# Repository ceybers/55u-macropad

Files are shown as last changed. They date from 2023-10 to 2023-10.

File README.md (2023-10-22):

# 5½u Macropad

## 📻 Project Description

A macropad inspired by the look of the iconic beam spring keyboards of the '70s.

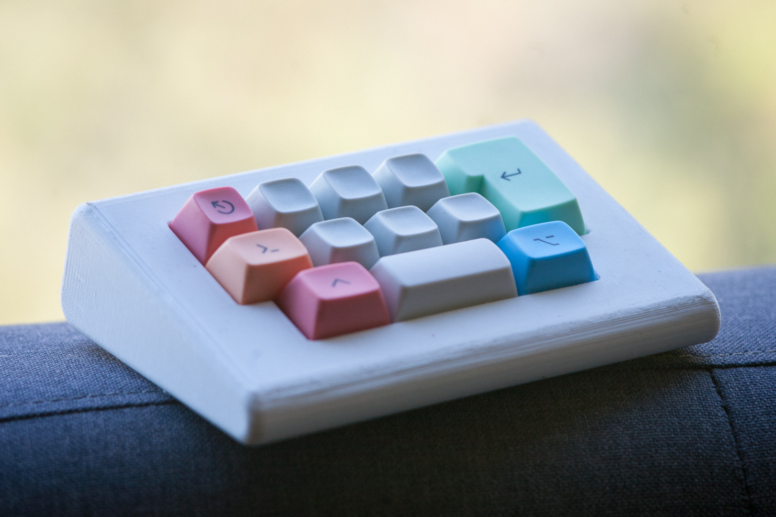
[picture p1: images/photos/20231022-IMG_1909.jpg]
Photo of the macro pad


## 🧰 Features

- 12× keys
- RP2040 microcontroller
- Powered by QMK with Vial support
- USB-C connector

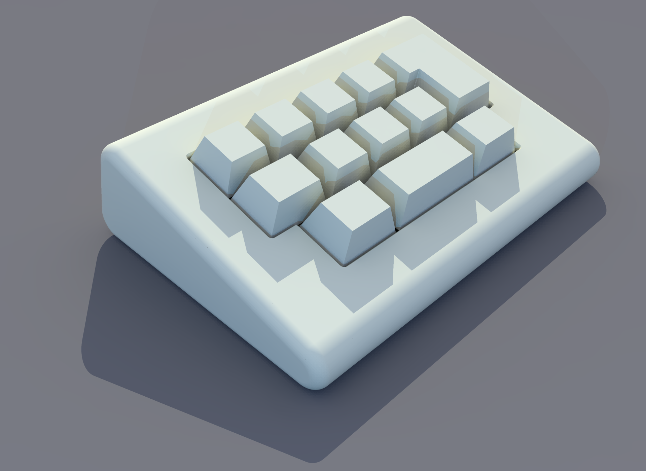
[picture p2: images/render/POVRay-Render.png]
Render using POVRay


## 📚 Read more...
- [Design](notes/Design.md)
- [Construction](notes/Construction.md)
- [Firmware](notes/Firmware.md)

---

## 🔗 Inspired by...
- [QAZER_BEAM](https://github.com/ImYourHuckleberry/QAZER_BEAM)
- [IBM Beam Spring Keyboards](https://deskthority.net/wiki/IBM_Beam_Spring_Keyboards#3275_.26_3277)
- [EzyezII Frankenstein](https://ezykeys.com/products/frankenstein-extensible-mini-mechanical-keyboard-kit)
- [Cary Works ViewEdge](https://drop.com/buy/cary-works-viewedge-display-and-c11-macropad)

## 📐 References
- [Raspberry Pi Pico Pinout](https://www.raspberrypi.com/documentation/microcontrollers/raspberry-pi-pico.html#pinout-and-design-files)
- [USB Type-C Breakout](https://www.pololu.com/product/3411)
- [QMK Firmware](https://docs.qmk.fm/)
- [Vial Firmware](https://get.vial.today/)

---

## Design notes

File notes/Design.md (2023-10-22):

# Design
The original design was a macro pad coupled with a LCD screen that would resemble a '70s or '80s terminal with a small CRT screen set in a bulky case. After some to and fro I decided to focus on the keyboard only as a separate piece.

Heavily inspired by ImYourHuckleberry's [QAZER_BEAM](https://github.com/ImYourHuckleberry/QAZER_BEAM), the aim I had in mind was a macropad that had generous bezels, a significant slope, and oversized round fillets. While it would only have 12 keys, I still wanted the familiar silhouette of a vintage keyboard. Lastly, I wanted the profile to hide the actual switches, with the keycaps sitting almost flush with the top surface.

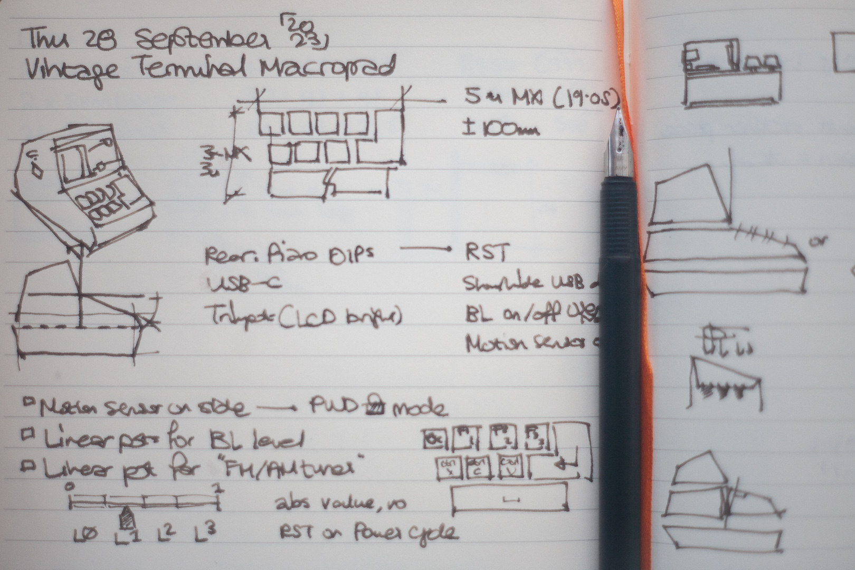
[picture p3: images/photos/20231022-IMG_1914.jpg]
Pen and paper sketch #1


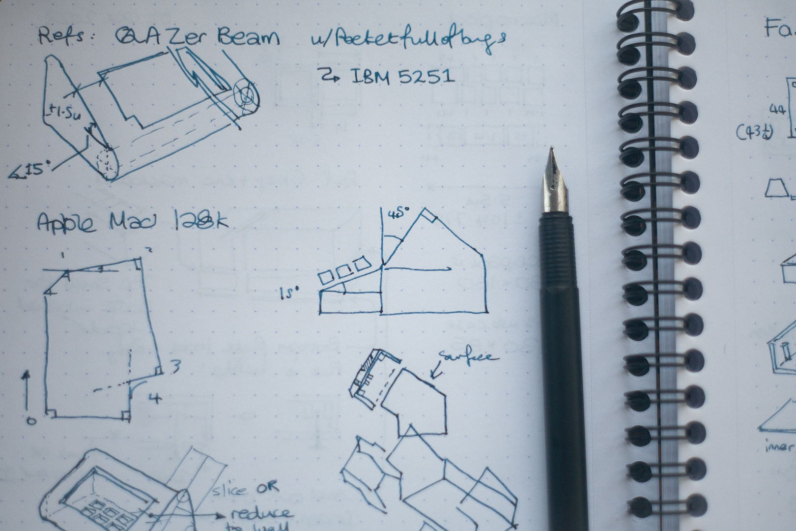
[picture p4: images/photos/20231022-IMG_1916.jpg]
Pen and paper sketch #2


Once I finished the pen and paper drafting and had a better idea of what I wanted, I used FreeCAD to create the models. 

I decided to create the case as one body, with the plate for the key switches being a separate part. It would be inserted from below and secured using screws into heat-set inserts that would be mounted inside and under the bezels of the case.

The bottom plate, which would be slightly wider than the switch plate, would then follow behind it and be secured in a similar fashion. I did not want the bottom plate visible from the sides, so I placed the heat-set inserts so that the bottom plate would sit sligthly inset into the case once secured.

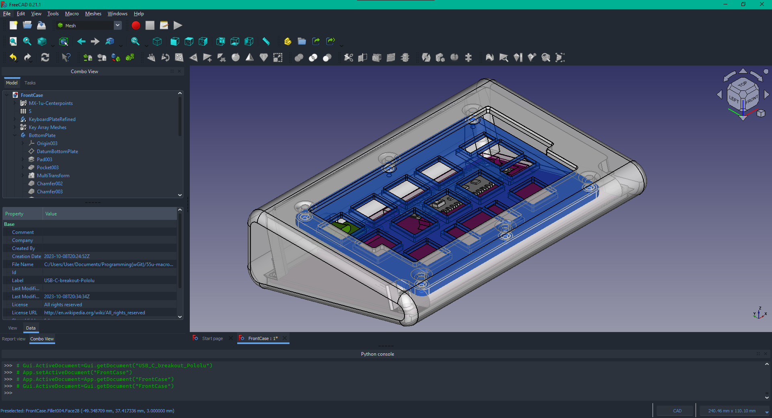
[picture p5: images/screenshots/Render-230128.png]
Render of the macro pad


---

Next: [Construction](Construction.md) | Back to [README.md](../README.md)

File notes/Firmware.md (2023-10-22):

# Firmware
## QMK and Vial
For the firmware I first used the official [QMK](https://docs.qmk.fm/) repo to ensure everything is working and wired up correctly. Once I had the QMK firmware working and flashed to the board, I installed the [Vial](https://get.vial.today/) fork of QMK, and created a Vial-compatible firmware using their instructions.

My initial attempt was to run QMK in a Docker container and then Vial in a separate container, but after some headscratching I instead spun up a new Linux LXC and just cloned both repos without using Docker.

I included the compiled firmware (`55u_macropad_vial.uf2`) for convenience. 

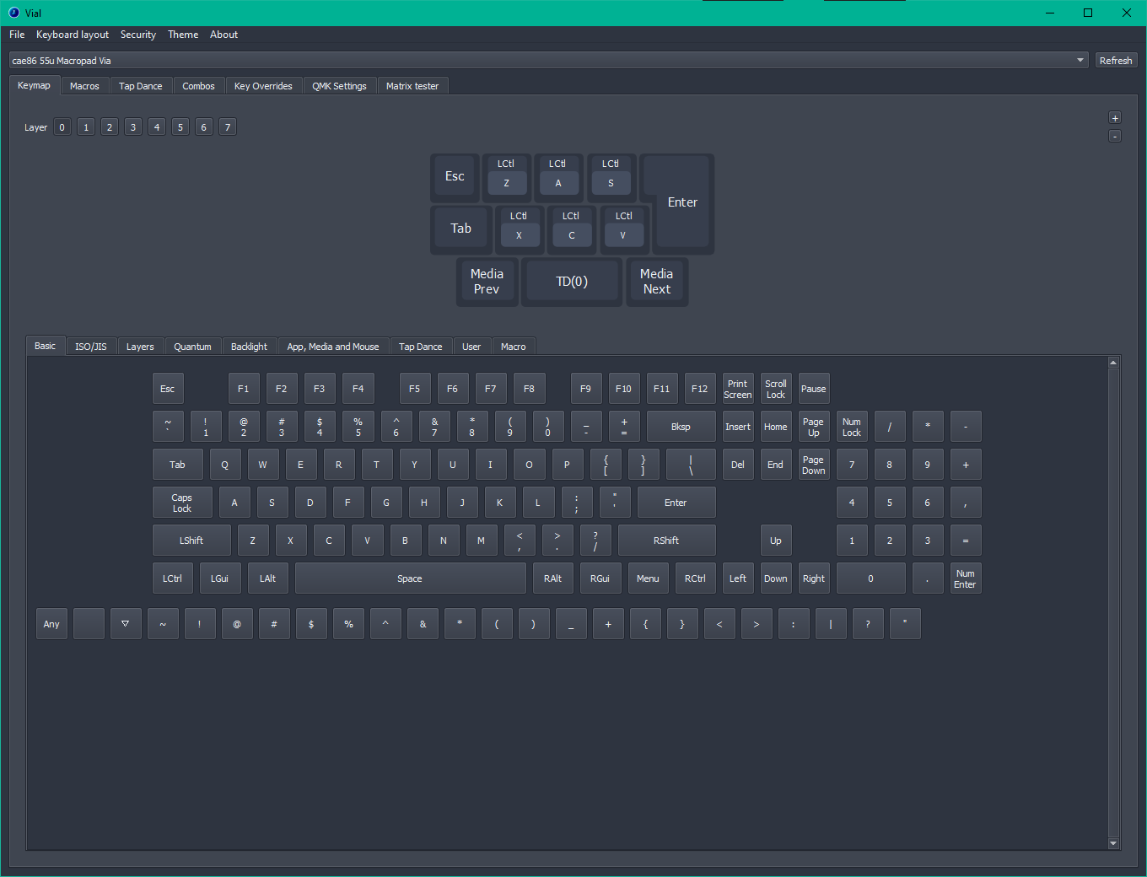
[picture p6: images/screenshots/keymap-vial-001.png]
Keymap in Vial #1

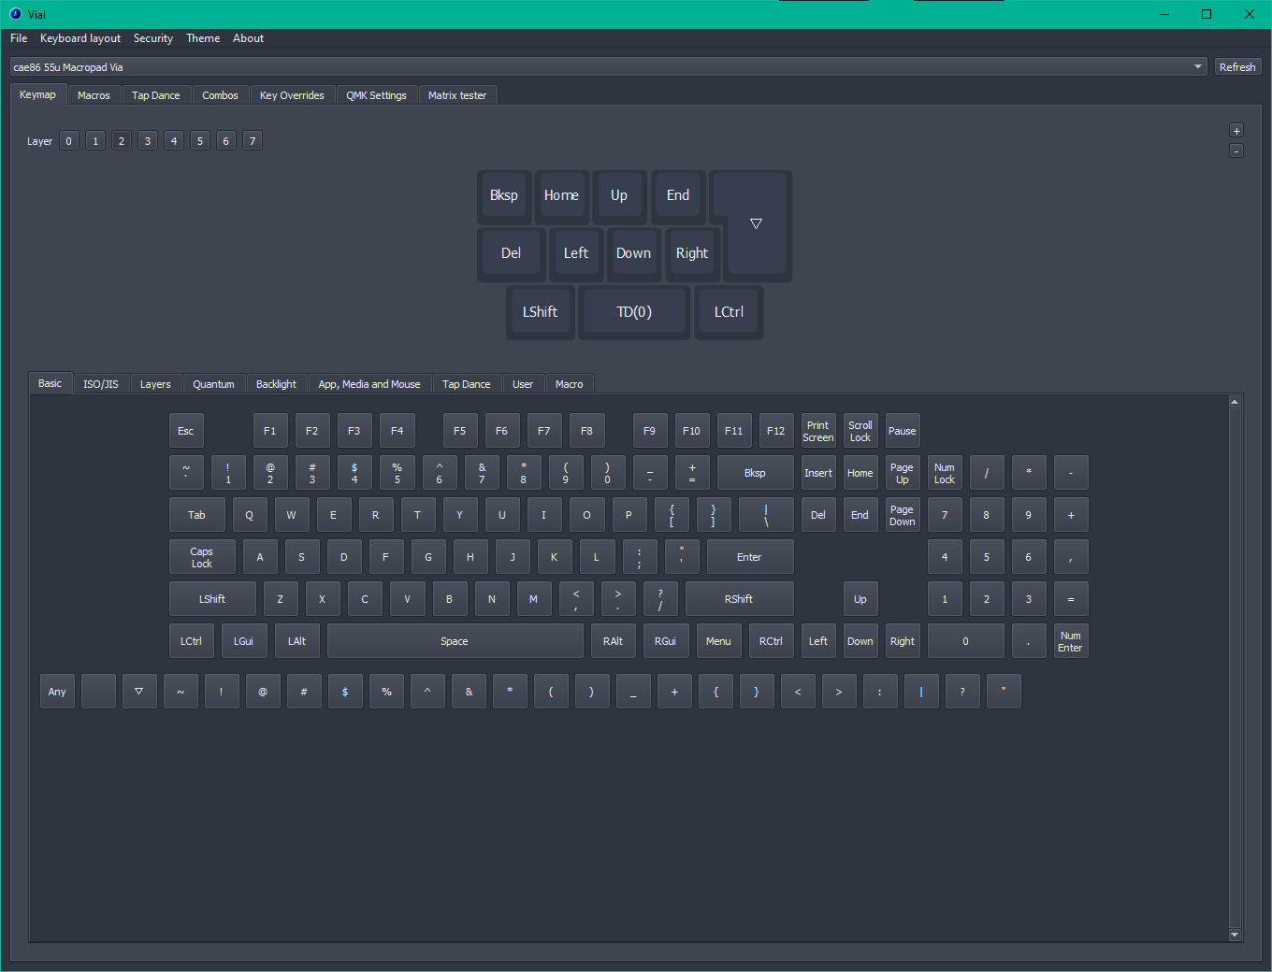
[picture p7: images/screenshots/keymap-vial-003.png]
Keymap in Vial #2


## Closing Thoughts
Like most macropads, I designed this for novelty rather than functionality or practicality. The main uses I have for it right now are having dedicated media keys (prev/pause/next), and having an Escape and Enter key when my main keyboard is connected via KVM to a different PC (since each PC has its own mouse).

I have some hotkeys such as Cut/Copy/Paste and Undo/Select All/Save as well, but I find it easier to just press the two keys on my main keyboard. In my experience having them on your main keyboard as Tap/Hold or Combos works much better.

I've considered adding text editor hotkeys such as column mode select or moving lines up/down, but again, having to move my hand to a separate device *and* having to change layers to use them does not feel very intuitive.

---

Back: [Construction](Construction.md)  | Back to [README.md](../README.md)

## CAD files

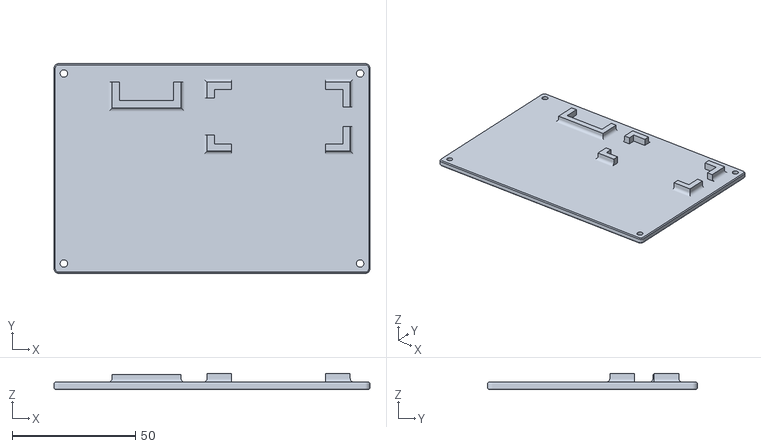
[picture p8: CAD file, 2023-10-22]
export/55u-macro-bottom-rev1.stl
128.0 x 85.0 x 6.50

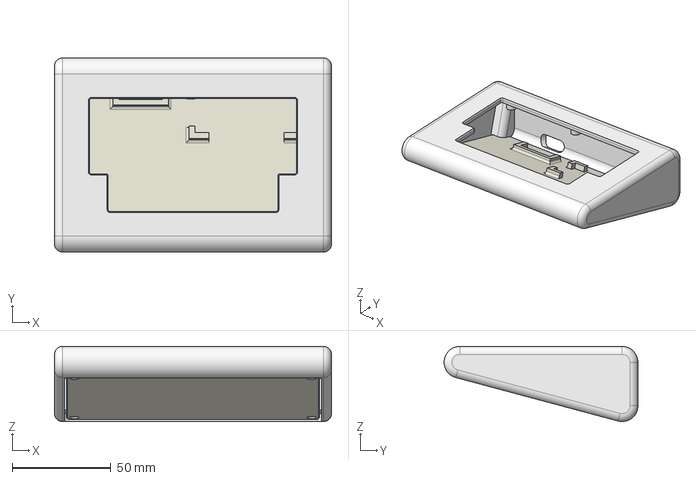
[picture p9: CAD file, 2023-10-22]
freecad/FrontCase.FCStd
140.0 x 98.0 x 38.0 mm
BottomPlate

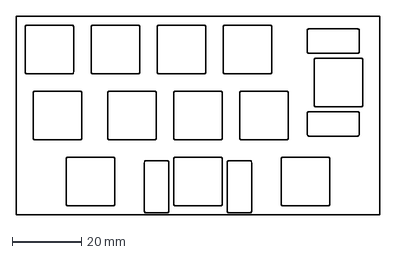
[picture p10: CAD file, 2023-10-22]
kle/plate-2023-10-08T14_36_38.846Z-with-stabs.dxf
104.8 x 57.1 mm

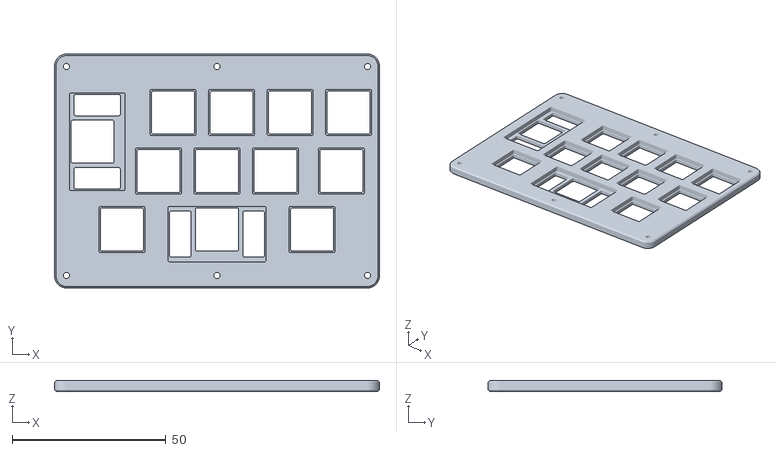
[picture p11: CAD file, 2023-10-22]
export/55u-macro-plate-rev1.stl
105.8 x 76.2 x 3.50

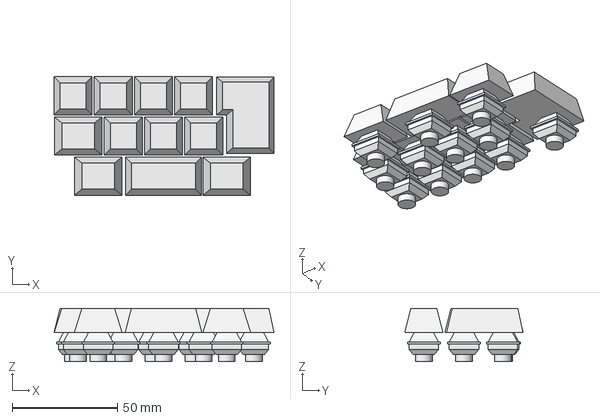
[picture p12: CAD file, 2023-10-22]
freecad/MXKeyArray.FCStd
104.3 x 56.2 x 25.3 mm

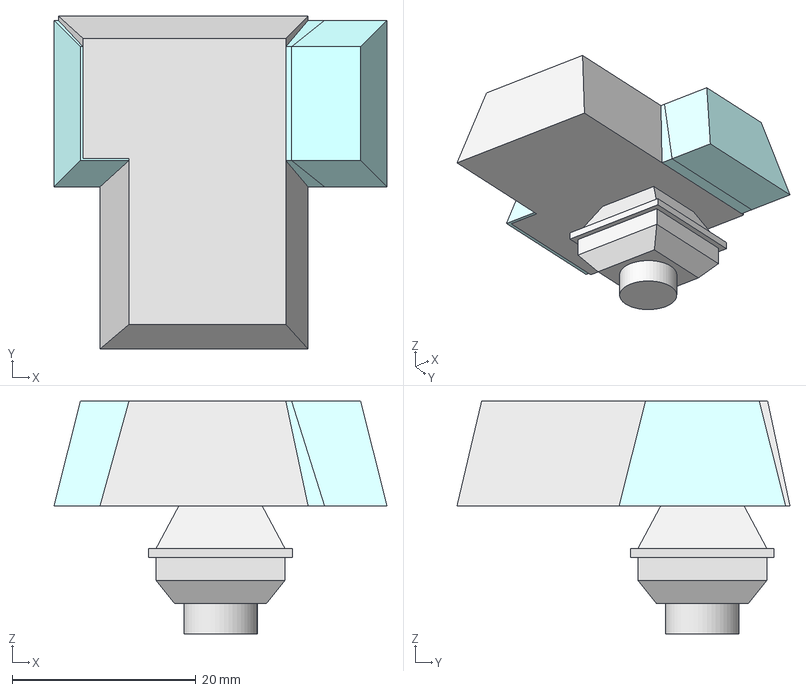
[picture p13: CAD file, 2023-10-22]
freecad/MX_Switches.FCStd
36.2 x 36.2 x 25.3 mm
MXSwitch100
MXSwitch125
MXSwitch200
MXSwitchIsoEnter

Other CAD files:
freecad/KeyboardPlate.FCStd

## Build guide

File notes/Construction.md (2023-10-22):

# Construction

## 🛒 Bill of Materials (BOM)

| Item | Size | Qty | 
| ---- | ---- | --- |
| Raspberry Pi Pico | N/A | 1 |
| [USB-C Breakout](https://www.pololu.com/product/3411) | N/A | 1 | 
| MX switches | N/A | 12 |
| Heat Set Inserts | M2 ø3.5×6mm | 6 |
| Heat Set Inserts | M3 ø4x5mm | 4 |
| Screws | M2 | 6 |
| Screws | M3 | 4 |
| Wire | 30AWG | N/A |
| 3D printed shell | N/A | 3 pcs |

## 📸 Photos
The plate is 3.5mm thick. The cutouts are 1.5mm x 14mm and 2.0mm x 15mm. However, in the second photo you can see the switches do not clip in cleanly. For my next plate I'll try changing the plate thickness to 1.4mm + 2.1mm to account for printer tolerances. I included cutouts for stabilizers but I didn't have any suitable pieces on hand to use.

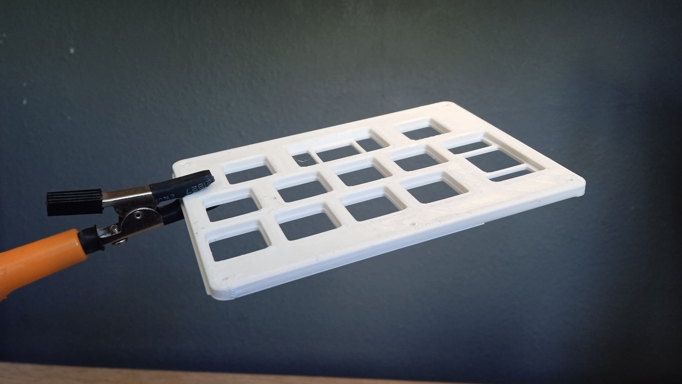
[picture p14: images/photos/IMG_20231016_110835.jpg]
Photo of the switch plate

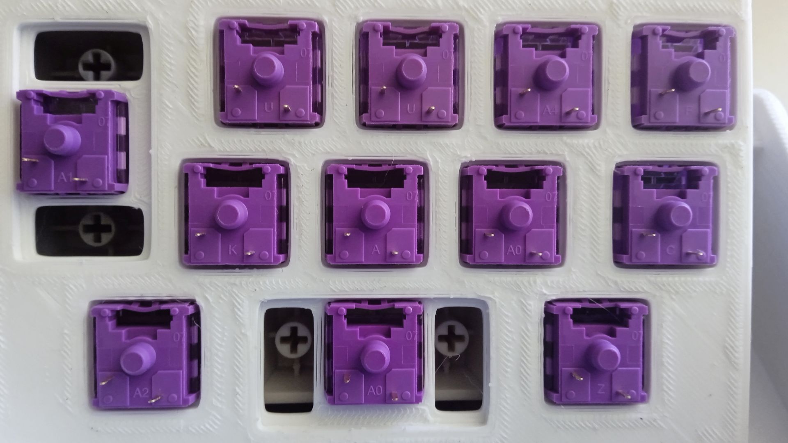
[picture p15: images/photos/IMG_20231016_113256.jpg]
Photo of the switches in the plate


The brackets to hold the boards in place fit decently. If I ever do a rev 2, I'd tighten the USB-C along the long side, and also raise the height slightly. This is to prevent the action of inserting the USB-C connector from dislodging it.

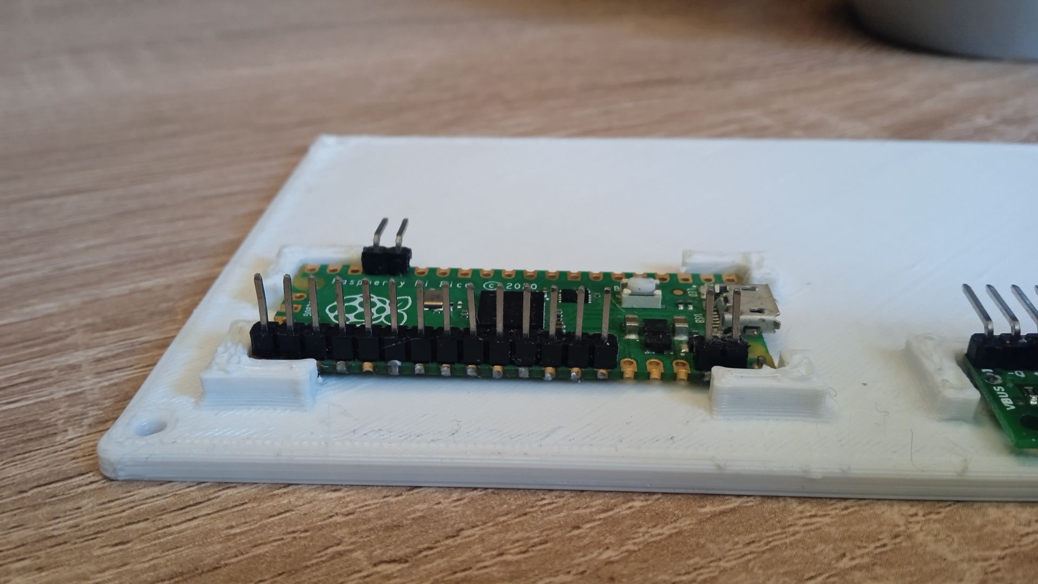
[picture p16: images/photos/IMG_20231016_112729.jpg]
Photo of the Raspberry Pico Pi

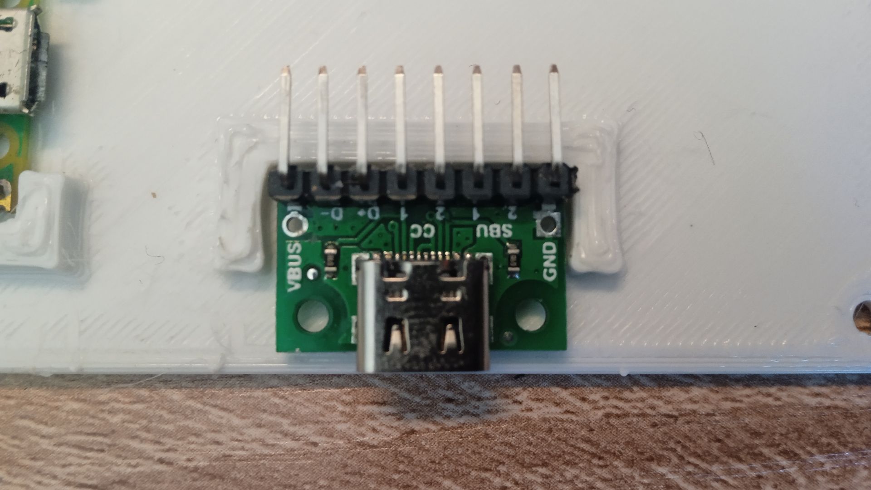
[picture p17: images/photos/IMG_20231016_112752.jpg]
Photo of the USB-C Breakout Board


The chamfer for the head of the M3 screws on the bottom lid were not large enough, and the screws stick out slightly. However because I am using adhesive bump-ons this is not a problem.

Additionally, the gap between the lid and the case to account for tolerances looks rather untidy — this is why I opted to have the case conceal the bottom lid when placed right side up.

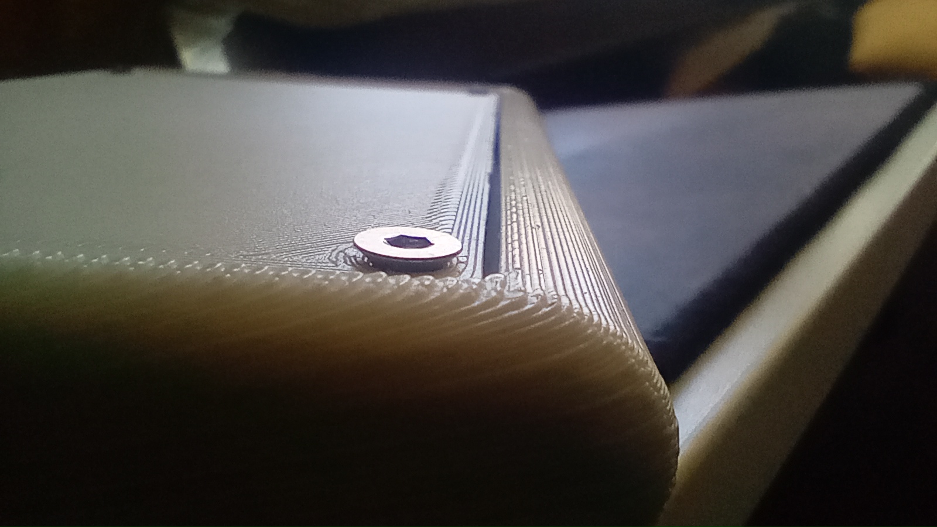
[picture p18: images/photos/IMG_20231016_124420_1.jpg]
Photo of the bottom lid and screw

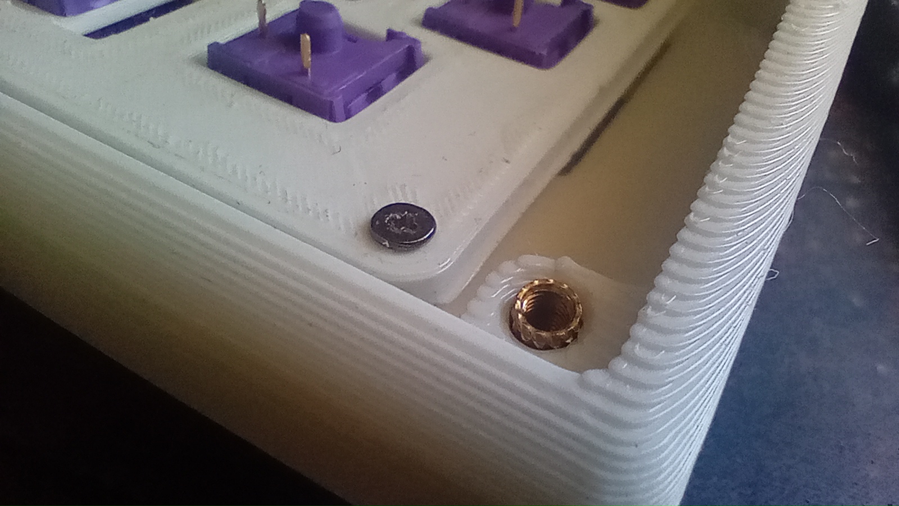
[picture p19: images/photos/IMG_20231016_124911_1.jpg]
Photo of a screw and a heat-set insert


Here you can see wires have been soldered to the TP pads on the back of the Pico. These connect to the USB-C breakout board. I was worried they would be too hard to solder but 30AWG wire, solder flux and Kapton tape made it managable. 

While this configuration works fine for USB Type-C to Type-A cables, if you wish to use Type-C to Type-C cables you will need resistors on the CC lines.

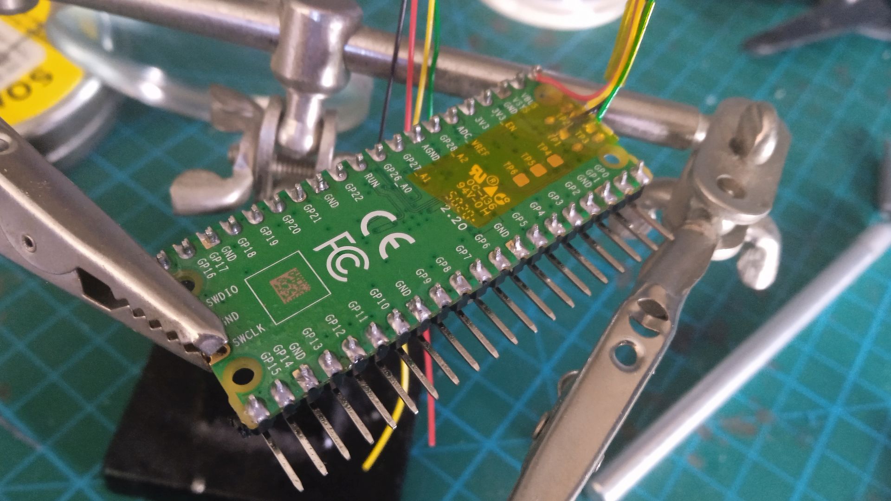
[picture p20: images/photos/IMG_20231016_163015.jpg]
Photo of the Pico being wired


---
Back: [Design](Design.md) | Next: [Firmware](Firmware.md) | Back to [README.md](../README.md)
